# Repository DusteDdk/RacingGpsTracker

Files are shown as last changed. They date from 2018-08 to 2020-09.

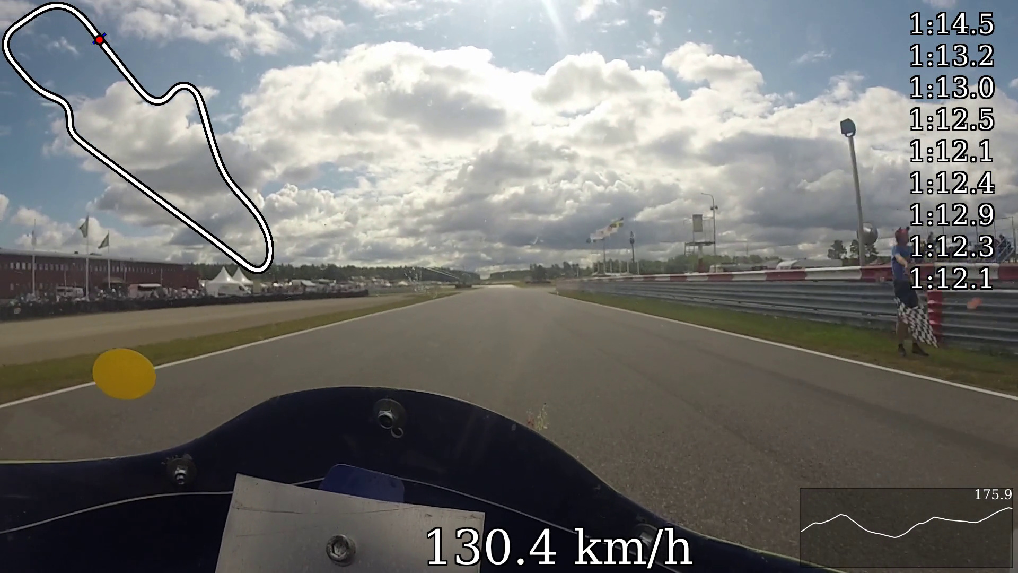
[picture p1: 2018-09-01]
framer/example/example.jpg

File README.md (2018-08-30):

Racing GPS Tracker
==================
Open Source solution for creating GPS video overlays for road-racing (and other stuff)

Projects
========

* framer    - Covert GPS stream data to video
* firmware  - Arduino firwmare to record GPS stream to sd card
* hardware  - How to build it
* case      - How to contain it

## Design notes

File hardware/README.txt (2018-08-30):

This is how stuff is put together.
I may do something more some time, but don't count on it.

     ^ = +5v, on the psu
     v =  0v, on the psu
    
     +-----+
     | GPS |
     |  +5 |--^ 
     | gnd |--v
     |  rx |---- tx on arduino
     |  tx |---- rx on arduino
     +-----+
    
     +------+
     |  SD  |
     |   +5 |--^
     |  gnd |--v
     | miso |---- 14 on arduino
     | mosi |---- 16 on arduino
     |  sck |---- 15 on arduino
     |   cs |----  9 on arduino
     +------+
    
     +-------+
     |arduino|
     |   vcc |--^ 
     |   gnd |--v  
     |     4 |->--- LED3 cathode, "recording" indicator
     |     5 |---- green wire, for uart mode (tx)
     |     6 |---- LED1 cathode, "waiting for fix" indicator
     |     7 |---- LED2 cathode, "got fix" indicator
     |     8 |---- yello wire, for uart mode (rx)
     +-------+
    
     +-----+
     | PSU |
     |  b+ |---- To the battery + terminal
     |  b- |---- To the battery - terminal
     |  p- |---- To toggle switch pole
     |   + |--^
     |   - |--v
     +-----+
    
     +-----------+
     | Toggle sw |
     | Terminal1 |---- To battery+
     | Terminal2 |---- To battery-
     +-----------+
    
     +---------+
     | Tact sw |
     |  Side 1 |--^
     |  Side 2 |------+------------- 3 on arduino
     +---------+      | +-----+
                      +-| 10k |--v
                        +-----+
    
     Repeat x3:
     +-----+
     | LED |     +------+
     |Anode|-----| 150r |--^
     +-----+     +------+

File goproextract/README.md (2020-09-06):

Extract gopro GPS data from video
==================
The Gopro hero 5 and later models are nice cameras and they can embed GPS data into the
video stream. Unfortunately, the software support is absolutely terrible, the program they
expect you to use is mainly for mobile phones (because we all know cellphones are super at
encoding high-bitrate 4k video and video editing.. Their "app" can't even stitch!).

getJsonFromVideo.js - extract GPS data from VIDEO into JSON
    usage: node getJsonFromVideo.js myFile.mp4 > gps.json

getNmeaFromJson.js - Convert GPS data into the truncated NMEA RMC format used by the framer program.
    usage: node getNmeaFromJson.js ./gps.json > track.rmc
    
    if you need to truncate multiple files, use >> merged.rmc on all file instead and then 
        remove all newlines: tr -d '\n' < merged.rmc > track.rmc.

Note: While gopro captures at ~18 hz, the framer was made with 10hz in mind, thus,
to get correct timing, and to generate a video that does not drift, getNmeaFromJson will
throw away gps samples to keep timing around 10hz, it's not pretty, and if you want it
to interpolate instead, then send me a pull request. But it's JUST FINE for generating nice
videos.

Example Workflow
======
Here i extract and combine gps data from 3 video files:

node getJsonFromVideo GX010005.MP4 > gps1.json
node getJsonFromVideo GX020005.MP4 > gps2.json
node getJsonFromVideo GX030005.MP4 > gps3.json

node getNmeaFromJson ./gps1.json > merged.rmc
node getNmeaFromJson ./gps2.json >> merged.rmc
node getNmeaFromJson ./gps3.json >> merged.rmc

tr -d '\n' < merged.rmc > final.rmc

mkdir out
./framer -in final.rmc -out out ... <-- follow instructions for how to use the framer.

ffmpeg -r 10 -i out/frame%06d.png -c:v png gps-overlay.mov

Then kdenlive and splice the videofiles and put the overlay on top.

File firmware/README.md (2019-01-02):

What's here
================
This is the firmware

The GPS thing, user manual
--------------------------
 # About
 # Usage -Recording
 # LED Indicators
 # Charging
 # Usage -Getting data out / removing files
 # The .RMC format

About
-----
The GPS thing is a GPS logger for racing which is very easy to use.
It writes GPS locations to a file 10 times per second when recording.
The format is a slightly mangled NMEA RMC message stream.
It was made for Road Racing, to record data for video overlay.
It is open-source, under the WTFPL.
Technical expertise is required for building, charging and extracting data,
but not for recording.

Usage - Recording
-----------------
Turn on, good idea to do it 10 minutes before, to get a solid fix, let it sit outside with clear view to sky.
Press button to start recording, the red light should be only one on.
Press button to stop recording.
If turned off while recording, up  to one minute of data may be lost (autosaves once per minute).
Recording can be started with or without signal.

LED indicators
--------------
From top to bottom (button is below LED3).

+-----+-----------+--------------------+---------------+----------------+
|     | Solid on  | 100 ms blinks      | 500 ms blinks | 1000 ms blinks |
+-----+-----------+--------------------+---------------+----------------+
|LED1 | Searching | Couldn't open      |               |                |
|     |           | file for recording |               |                |
+-----+-----------+--------------------+---------------+----------------+
|LED2 | Found SAT | No free filename   |               | SD Card        |
|     |           | for recording      |               | Init error     |
+-----+-----------+--------------------+---------------+----------------+
|LED3 | Recording |                    | Autosaving    |                |
|     |           |                    | failed        |                |
+-----+-----------+--------------------+---------------+----------------+
# LED1+LED2 Solid = UART Comms mode.

Charging
--------
Wire to a single-cell liion charger:
Gray - Negative
Red  - Positive

Usage - Getting data out / removing files
-----------------------------------------
Turn on while holding down the button. Both leds stay on, it is in uart mode.
Wire up the UART (there is enough power on the uart to keep the MCU alive, so wire GND after turning on)
Green wire: TTL UART TX
Yello wire: TTL UART RX
Black wire: Gnd for UART
Connect with uart speed: 28800  (which is 9600x3)
Press ? to view online help.
Press d to list directory
Press s to dump a file
Press r to remove a file
Backspace is not supporeted, if a typo is made, press enter and try again, unless pressing enter
would cause you to delete a file, and you didn't want it deleted, in that case, type more to ensure an invalid filename.

The .RMC format
---------------
Files are named according to %.2X.RMC.
There are no linebreaks in the file.
Each message is terminated with a pipe ( | ).
If one replaces all pipes with newlines, and prefixes all lines with "$GPRMC," (without "")
then the file is a standard NMEA RMC message stream.

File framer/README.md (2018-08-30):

The Framer
==========

Render overlay frames from GPS data, fit for usage in video

Building
========

go build

Usage
=====
Some tweaking is requierd, it's easiest to render a single, late frame, to determine what needs tweaking.
./framer --help     Show all the options

Example:
./framer -first 1450 -in 01.RMC -out out/ -trackFirst 95 -trackLast 8410 -finishAt 1685 -finishAngle -35  -firstLap 1 -lastLap 50

-first 1450         The first sample that is used is 1450
-in 01.RMC          The input file is 01.RMC
-out out/           out is an empty directory where the images will be ouput
-trackFirst         Start drawing track 95 samples after the first sample. (This allows the red dot to move outside the track at the start/end)
-trackLast 8410     Stop drawing track after sample 1685, so we don't draw the route out of the track
-finishAt 1685      Sample 1685 was taken very close to the place of the finish line (I eyeballed it!)
-finishAngle -35    Rotate the finish-line -35 degrees so that it crosses the track (eyeballed)
-firstLap 1         Skip the first lap (0), and use lap 1 as the first lap, lap0 was in this case begun when driving onto the track
-lastLap 8          Stop after 8 laps (lap 0 is ignored), since the last lap was just slow driving into pit

Generate video overlays
=======================

Check the scripts:
render-alignment-video.sh - For quickly rendering a video which can be used to line-up GPS data and video, this is a throwaway video..
render-video.sh - Overlay the image files from the output directory onto the target video (generates new viedo)

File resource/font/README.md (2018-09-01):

Some bug in some go lib
=======================

If your framer binary complains about a missing font,
put something called luxisr.ttf here.

The following worked for me:

cp /usr/share/fonts/truetype/dejavu/DejaVuSerif.ttf luxisr.ttf

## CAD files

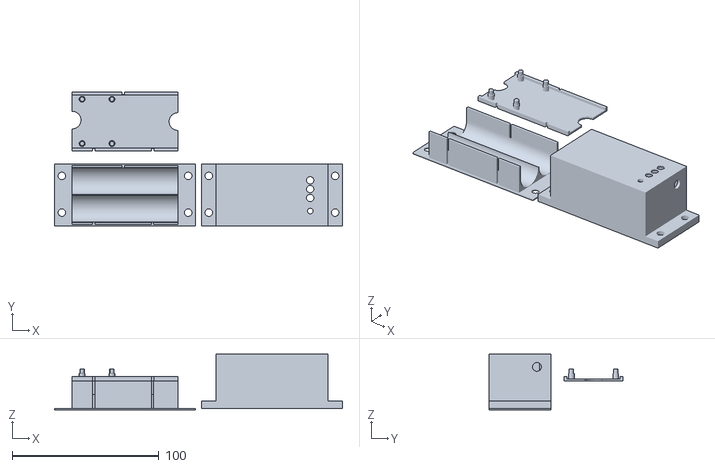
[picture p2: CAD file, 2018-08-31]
case/smallgps.stl
196.0 x 91.0 x 37.9

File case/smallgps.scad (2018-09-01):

    // 
    
    batLength=72;
    batDia=18.25;
    module battery() {
        rotate( [ 0,90,0 ] )
        cylinder( batLength, batDia/2, batDia/2);
    }
    
    module batteries() {
        color( [0.5,0.5,1] ) {
            translate( [0,batDia/2+0.25,0 ] )
            battery();
            translate( [0,-batDia/2-0.25,0 ] )
            battery();
        }
    } 
    
    
    
    gpsBoardWidth=26.4;
    gpsBoardHeight=35.7;
    gpsBoardDepth=3.7;
    gpsAntOffset=4.9; // from bottom
    gpsAntWidth=25.5;
    gpsAntHeight=25.5;
    gpsAntDepth=9.6;
    module gpsModule(antSpace) {
        
        color([1,1,0] )
        difference() {
            cube([gpsBoardWidth, gpsBoardHeight, 1.3] );
    
            translate( [1.5+1.3, 1+1.5, -1 ] )
            cylinder(10, 1.5, 1.5);
            translate( [1.5+1.3, gpsBoardHeight-1.5-1.5, -1 ] )
            cylinder(10, 1.5, 1.5);
    
            translate( [gpsBoardWidth-1.5-1.8, 1+1.5, -1 ] )
            cylinder(10, 1.5, 1.5);
            translate( [gpsBoardWidth-1.5-1.8, gpsBoardHeight-1.5-1.5, -1 ] )
            cylinder(10, 1.5, 1.5);
    
        }
        translate( [ 0, gpsAntOffset, 1.3 ] )
        color([1,0,0] )
        cube([gpsBoardWidth, gpsAntHeight, gpsAntDepth] );
    
        if(antSpace) {
            translate( [ -2, gpsAntOffset-2, 1.3 ] )
            color([1,1,0] )
            cube([gpsBoardWidth+4, gpsAntHeight+4, gpsAntDepth+2] );
        }
    }
    
    
    
    psuWidth=38.2;
    psuHeight=5.8;
    psuDepth=9.7;
    module psuPcb() {
        color([1,0,0])
        cube( [psuWidth, psuHeight, psuDepth] );
    }
    
    
    mcuWidth=33.1;
    mcuHeight=4.9;
    mcuDepth=18.3;
    
    mcuUsbOffset=5.4;
    mcuUsbHeight=3.5;
    mcuUsbDepth=8.5;
    
    module mcuPcb() {
        cube( [mcuWidth, mcuHeight, mcuDepth ] );
        translate( mcuPcbOffset )
        translate( [mcuWidth-1,0,mcuUsbOffset])
        cube( [10, mcuUsbHeight, mcuUsbDepth ] );
    }
    
    sdWidth=38.2;
    sdHeight=7;
    sdDepth=18;
    sdSlotOffset=1.6;
    sdSlotDepth=13.5;
    sdSlotHeight=2.7;
    module sdPcb() {
        cube( [sdWidth, sdHeight, sdDepth ] );
        translate( sdOffset )
        translate( [sdWidth-1,0,sdSlotOffset] )
        cube( [  10, sdSlotHeight, sdSlotDepth ] );
    }
    
    swWidth=14;
    swHeight=13.05;
    swDepth=7;
    swDia=6;
    module switch() {
        color( [ 1,1,0 ] )
        cube( [swWidth, swHeight, swDepth ] );
        
        translate(swOffset)
        translate( [10, swHeight/2,swDepth/2 ] )
        rotate( [0,90,0 ] )
        cylinder( 10, swDia/2, swDia/2 );
    }
    
    btnWidth=6.18;
    btnDepth=4;
    btnDia=3.8;
    module btn() {
        cube( [btnWidth, btnWidth, btnDepth] );
        translate([ btnWidth/2, btnWidth/2, btnDepth])
        cylinder( 10, btnDia/2, btnDia/2 );
    }
    
    
    module gpsmnt(h,r) {
        
        translate( [1.5+1.3, 1+1.5, -1 ] )
        cylinder(h, r, r);
        translate( [1.5+1.3, gpsBoardHeight-1.5-1.5, -1 ] )
        cylinder(h, r, r);
    
        translate( [gpsBoardWidth-1.5-1.8, 1+1.5, -1 ] )
        cylinder(h, r, r);
        translate( [gpsBoardWidth-1.5-1.8, gpsBoardHeight-1.5-1.5, -1 ] )
        cylinder(h, r, r);
       
    }
    
    w=40;
    $fn=90;
    module topPlate() {
        
        translate([-4,-3,-3]) difference() {
            cube( [batLength, w, 3] );    
            translate([-1,2,1.4]) cube( [batLength+2, w-4, 3] );    
            
            translate([0,21,-3]) cylinder( 10,6,6 );
            translate([batLength,w/2,-3]) cylinder( 10,6,6 );
    
    
        }
    }
    //btn();
    module batbox() {
        difference() {
            translate([0, -w/2,-batDia/2-0.3])
            cube([batLength, w, batDia/2+0.3]);
            batteries();
        }
        
        translate([0, -w/2,0])
        cube([batLength, 1.4, batDia/2+0.2]);
        translate([0, -1.4+w/2,0])
        cube([batLength, 1.4, batDia/2+0.2]);
    }
    
    module rails() {    
            translate( [10,0,0] ) cube([1.5,1.5,21.725+15]);
            translate( [50,0,0] ) cube([1.5,1.5,21.725+15]);
            translate( [30,40-1.5,0] ) cube([1.5,1.5,21.725+15]);
    }
    
    module rails2() {    
    
            translate( [10-0.03,0,0] ) cube([1.6,1.6,21.725+15]);
    
            translate( [50,0,0] ) cube([1.5,1.5,21.725+15]);
    
            translate( [50-0.03,0,0] ) cube([1.6,1.6,21.725+15]);
    
            translate( [30-0.03,40-1.6,0] ) cube([1.6,1.6,21.725+15]);
    
    }
    
    
    module middle()  {
        difference() {
            topPlate();
            translate([0,-3,-21.725]) rails2();
        }
    
        translate([0,-0.5,-2]) gpsmnt(8, 1.5);
        translate([0,-0.5,-2]) gpsmnt(3+2, 2.0);
    }
    
    
    
    module bottom() {
    
    
    difference() {
        translate([-4,17,-12.3]) batbox();
        translate([0,-3,-21.725]) rails();
    
    }
    
    difference() {
        color([1,0,0]) translate([-6,-4,-12.3]) translate([-10,0,-10.425]) cube( [76+20,42, 1] );
        studs();
    }
    
    }
    
    
    //translate([-4,17,-12.3]) batteries();
    
    //translate([0,-0.5,2.0 ]) gpsModule(false);
    
    //    topPlate();
    
    //translate([0,-0.5,2.0 ]) gpsModule(false);
      //translate([-6,-4,-21.725]) shell();
    
    
    module shell() {
        cube( [76,42,36.9] );
        translate([-10,0,0]) cube( [76+20,42, 5] );
        
    }
    
    module studs() {
        translate([-11,5,-25]) cylinder(10,2.55, 2.55);
        translate([-11,30,-25]) cylinder(10,2.55, 2.55);
        translate([75,5,-25]) cylinder(10,2.55, 2.55);
        translate([75,30,-25]) cylinder(10,2.55, 2.55);
    }
    
    
    
    module top() {
    difference() {
        translate([-6,-4,-21.725]) shell();
        translate([-4,-3,-21.725-1]) cube( [72,40,36.9] );
        translate([0,-0.5,2.0 ]) gpsModule(true);
        translate([55,3,10.5]) btn();
        translate([55+3, 42/2-6, 10.5]) cylinder(100,2.5,2.5);
        translate([55+3, 42/2-6+6, 10.5]) cylinder(100,2.5,2.5);
        translate([55+3, 42/2-6+6+6, 10.5]) cylinder(100,2.5,2.5);
        translate([54,22,3]) rotate([0,0,0]) switch();
        studs();
        
    }
    
      difference() {
        translate([-4,-3,-3]) difference() {
            color([1,0,0]) cube( [batLength, w, 18.1] );    
            translate([-1,1.5,-1]) cube( [batLength+2, w-3, 100] );    
    
        }
    
    
        translate([-4,-3,-3]) difference() {
            cube( [batLength, w, 3] );    
            translate([-1,1.5,-1]) cube( [batLength+2, w-3, 10] );    
    
        }
    }
    
    translate([0,-3,-21.725]) rails();
    
    difference() {
        translate([0,-0.5,4.4]) gpsmnt(3+4+4.77, 2.0);
        translate([0,-0.5,-1]) gpsmnt(8, 1.55);
    }
    
    
    difference() {
        translate([55-1,2,12]) cube([btnWidth+2,btnWidth+2, 3.0]);
        translate([55,3,10.5]) btn();
    }
    }


// Here are the parts, render one at a time!
// Remove the translations if you like.. just there because they look cool
translate([100,0,0 ]) top();
//translate([0,50,0 ] ) middle();
//bottom();

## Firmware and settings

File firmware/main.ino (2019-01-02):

#include <SPI.h>
#include <SD.h>
#include <SoftwareSerial.h>



const int SDCSPIN = 9;
const int FOUNDPIN = 7;
const int SRCHPIN = 6;
const int RECPIN = 5;
const int BTNPIN = 3;

const int RXPIN = 8;    // Receive = Yellow
const int TXPIN = 4;    // Transmit = Green
                        /// GNDPIN = Black


inline int nmeaSum(const char *msg)
{
    int checksum = 0;
    for (int i = 0; msg[i] && i < 32; i++)
        checksum ^= (unsigned char)msg[i];

    return checksum;
}

void nmeaWrite(char* msg) {

  char checkStr[8];
  snprintf(checkStr,7, "*%.2X", nmeaSum(msg));
  Serial1.print("$");
  Serial1.print(msg);
  Serial1.println(checkStr);
}

void nmeaDisable(char* nam) {
  char buf[32];
  snprintf(buf, 31,"PUBX,40,%s,0,0,0,0", nam);
  nmeaWrite(buf);
}

const unsigned char UBLOX_SLOW_RATE[] PROGMEM = {0xB5,0x62,0x06,0x08,0x06,0x00,0xE8,0x03,0x01,0x00,0x01,0x00,0x01,0x39};
void setSlow() {
    for(unsigned int i = 0; i < sizeof(UBLOX_SLOW_RATE); i++) {                       
    Serial1.write( pgm_read_byte(UBLOX_SLOW_RATE+i) );
  }
}

const unsigned char UBLOX_FAST_RATE[] PROGMEM = {0xB5,0x62,0x06,0x08,0x06,0x00,0x64,0x00,0x01,0x00,0x01,0x00,0x7A,0x12};

void setFast() {
    for(unsigned int i = 0; i < sizeof(UBLOX_FAST_RATE); i++) {                       
    Serial1.write( pgm_read_byte(UBLOX_FAST_RATE+i) );
  }
}

void showHelp(SoftwareSerial* ss) {
  ss->println("?=this sNAME=show rNAME=remove d=dir");
}

File root;
void setup() {
  // put your setup code here, to run once:
  pinMode(SDCSPIN, OUTPUT);

  pinMode(SRCHPIN, OUTPUT);
  digitalWrite(SRCHPIN, LOW);

  pinMode(FOUNDPIN, OUTPUT);
  digitalWrite(FOUNDPIN, LOW);

  pinMode(RECPIN, OUTPUT);
  digitalWrite(RECPIN, HIGH);
  
  pinMode(BTNPIN, INPUT);
  digitalWrite(BTNPIN, LOW);




  /*Serial.begin(9600);
  while (!Serial) {
    ; // wait for serial port to connect. Needed for native USB port only
  }
*/
 //Serial.print("Initializing SD card...");

  if (!SD.begin(SDCSPIN)) {
//    Serial.println("initialization failed!");
//    while (1);

    err(FOUNDPIN, 1000);
  }

  delay(50);
  if(digitalRead(BTNPIN)) {
    pinMode(RXPIN, INPUT);
    pinMode(TXPIN, OUTPUT);
    SoftwareSerial ss(RXPIN, TXPIN);

      ss.begin(28800);
      showHelp(&ss);
      uint8_t mode=0;
      char buf[17];
      uint8_t cur=0;
      while(1) {
        if(mode==0) {
          switch( ss.read() ) {
            case '?':
            showHelp(&ss);
            break; 
            case 'd':            
            root=SD.open("/");
            root.rewindDirectory();
            if(!root) {
              ss.println("ERR opening dir.");
            }
            while(1) {
              File entry=root.openNextFile();
              if(!entry) {
                break;
              }
              ss.print(entry.name());
              if (entry.isDirectory()) {
                ss.println("/");
              } else {
                // files have sizes, directories do not
                ss.print("\t");
                ss.println(entry.size(), DEC);
              }
              entry.close();
            }
            root.close();
            break;
            case 's':
              ss.print("Show:");
              mode=1;
              cur=0;
              memset(buf,0,16);
            break;
            case 'r':
              ss.print("Remove:");
              mode=2;
              cur=0;
              memset(buf,0,16);
            break;
          }
        } else if(mode==1) {
          if(ss.available()>0) {
            uint8_t c = ss.read();
            if(c==10) {
            } else if(c==13) {
              buf[cur]=0;
              cur=0;
              mode=0;
              ss.println();
              ss.print("<");
              ss.print(buf);
              ss.println(">");
              File f=SD.open(buf, FILE_READ);
              if(!f) {
                ss.println("ERR");
              } else {
                memset(buf,0,17);
                while( f.read(buf, 16) > 0 ) {
                  ss.print(buf);
                  memset(buf,0,16);
                }

                f.close();
                ss.println("<EOF>");
                
              }
            } else {
              if(cur==16) {
                cur=0;
                mode=0;
                ss.println("ERR");
              } else {
                ss.print((char)c);
                buf[cur]=c;
                cur++;
              }
            }
          }
          
        } else  if(mode==2) {
          if(ss.available()>0) {
            uint8_t c = ss.read();
            if(c==10) {
            } else if(c==13) {
              buf[cur]=0;
              cur=0;
              mode=0;
              ss.println();
              if(SD.remove(buf)) {
                ss.println("REMOVED");
              } else {
                ss.println("ERR");
              }
            } else {
              if(cur==16) {
                cur=0;
                mode=0;
                ss.println("ERR");
              } else {
                ss.print((char)c);
                buf[cur]=c;
                cur++;
              }
            }
          }
          
        }
        
      }
     
  }


//  Serial.println("Gps?");
  Serial1.begin(9600);
  // delay a bit
  delay(500);
//  Serial.println("Gps!");
  setSlow();
  nmeaDisable("VTG");
  nmeaDisable("GGA");
  nmeaDisable("GSA");
  nmeaDisable("GSV");
  nmeaDisable("GLL");


}

void err(uint8_t pin, int d) {
  // Turn them all off
  digitalWrite(FOUNDPIN, HIGH);
  digitalWrite(SRCHPIN, HIGH);
  digitalWrite(RECPIN, HIGH);
  // Enter infinite loop.
    while(1) {
      digitalWrite(pin, LOW);
      delay(d);
      digitalWrite(pin, HIGH);
      delay(d);
    }
}


char buf[128];
uint8_t ci=0;

char recFileName[16];
File recFile;
uint8_t recording=0;
int sample=0;

void saveAndReopen() {
  recFile.close();
  recFile=SD.open(recFileName, FILE_WRITE);
  if(!recFile) {
    err(RECPIN,500);
  }
}

void startRecord() {
  recording=1;
  sample=0;
  ci=0;

  for(uint8_t i=0; i < 256; i++) {

    snprintf(recFileName,15,"%.2X.rmc", i);

    if(!SD.exists(recFileName)) {
      break;
    }
    
    if(i==255) {
      err(FOUNDPIN,100);
    }
  }

  recFile=SD.open(recFileName, FILE_WRITE);

  if(!recFile) {
    err(SRCHPIN, 100);
  }

  digitalWrite(FOUNDPIN, HIGH);
  digitalWrite(SRCHPIN, HIGH);
  digitalWrite(RECPIN, LOW);

  
  while(Serial1.available()>0) {
    Serial1.read();
  }
  setFast();
}

void stopRecord() {
  digitalWrite(FOUNDPIN, HIGH);
  digitalWrite(SRCHPIN, HIGH);
  digitalWrite(RECPIN, HIGH);
  setSlow();
  recording=0;
  recFile.close();

}

void loop() {

 // Serial.println(digitalRead(BTNPIN));

  //Button
  if( digitalRead(BTNPIN) ) {
    //Serial.println("Btn push if");
    delay(500);
    while(digitalRead(BTNPIN)) {
      //Serial.println("Btn push while");
      delay(1000);
    }

    if(recording) {
      Serial.println("Stop record");
      stopRecord();
    } else {
      Serial.println("Start record");
      startRecord();
    }
  }


  //GPS stuff
  while( Serial1.available() > 0 ) {
    char c=Serial1.read();
    
    if(c==13) {
      //Just skip it (I guess this can't be optimized out, right?)
    } else if(c==10) {

      buf[ci]='|';
      buf[ci+1]=0;
        
      //Got message, let's see if it's valid:
      //$GPRMC,,V,,,,,,,,,,N*53
      //$GPRMC,224439.00,V,,,,,,,120718,,,N*7A
      //$GPRMC,165328.00,A,5707.38417,N,00937.64974,E,0.041,,120718,,,A*7A
      if(!recording && ci>17) {
        if(buf[17]=='A') {
          digitalWrite(SRCHPIN,HIGH );
          digitalWrite(FOUNDPIN,LOW);
        } else {
          digitalWrite(FOUNDPIN,HIGH);
          digitalWrite(SRCHPIN,LOW );
        }
      } else if(recording && ci > 17) {
        if(buf[3]=='R' && buf[4]=='M' && buf[5]=='C') {
          recFile.write(buf+7, ci+1-7);

          sample++;
          if(sample==600) {
            sample=0;
            saveAndReopen();
          }
        }
      }
      ci=0;    

    } else {
      buf[ci]=c;
      ci++;
    }
  }
}

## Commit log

2018-08-31 Updated framer, added case scad and stl
    [smallgps.scad, smallgps.stl]
2018-09-01 Added example commands / rmc file
    [smallgps.scad]
2020-09-06 Tool to extract embedded GPS data from GoPro videos + some tweaks to framer
